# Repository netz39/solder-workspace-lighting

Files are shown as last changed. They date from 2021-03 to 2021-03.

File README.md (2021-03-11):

# solder workspace lighting
*Created with KiCad 5.1.9*

Dieses Repo beinhaltet die drei notwendigen Platinen, um den Lötarbeitsplatz im Netz39 ordentlich auszuleuchten.

## central_control
Überwacht die Temperatur aller LED-Projektoren und betreibt PWM-Dimming. Desweiteren bietet die Platine mehrere Schnittstellen (UART, SPI, I²C, CAN) für Erweiterungen an

## constant_current_source
Ein Buck-Converter liefert den voreingestellten konstanten Strom für die LEDs.

## high_power_LED:
Bestückt mit HighPower-LEDs, Thermistor und Kühlkörper.

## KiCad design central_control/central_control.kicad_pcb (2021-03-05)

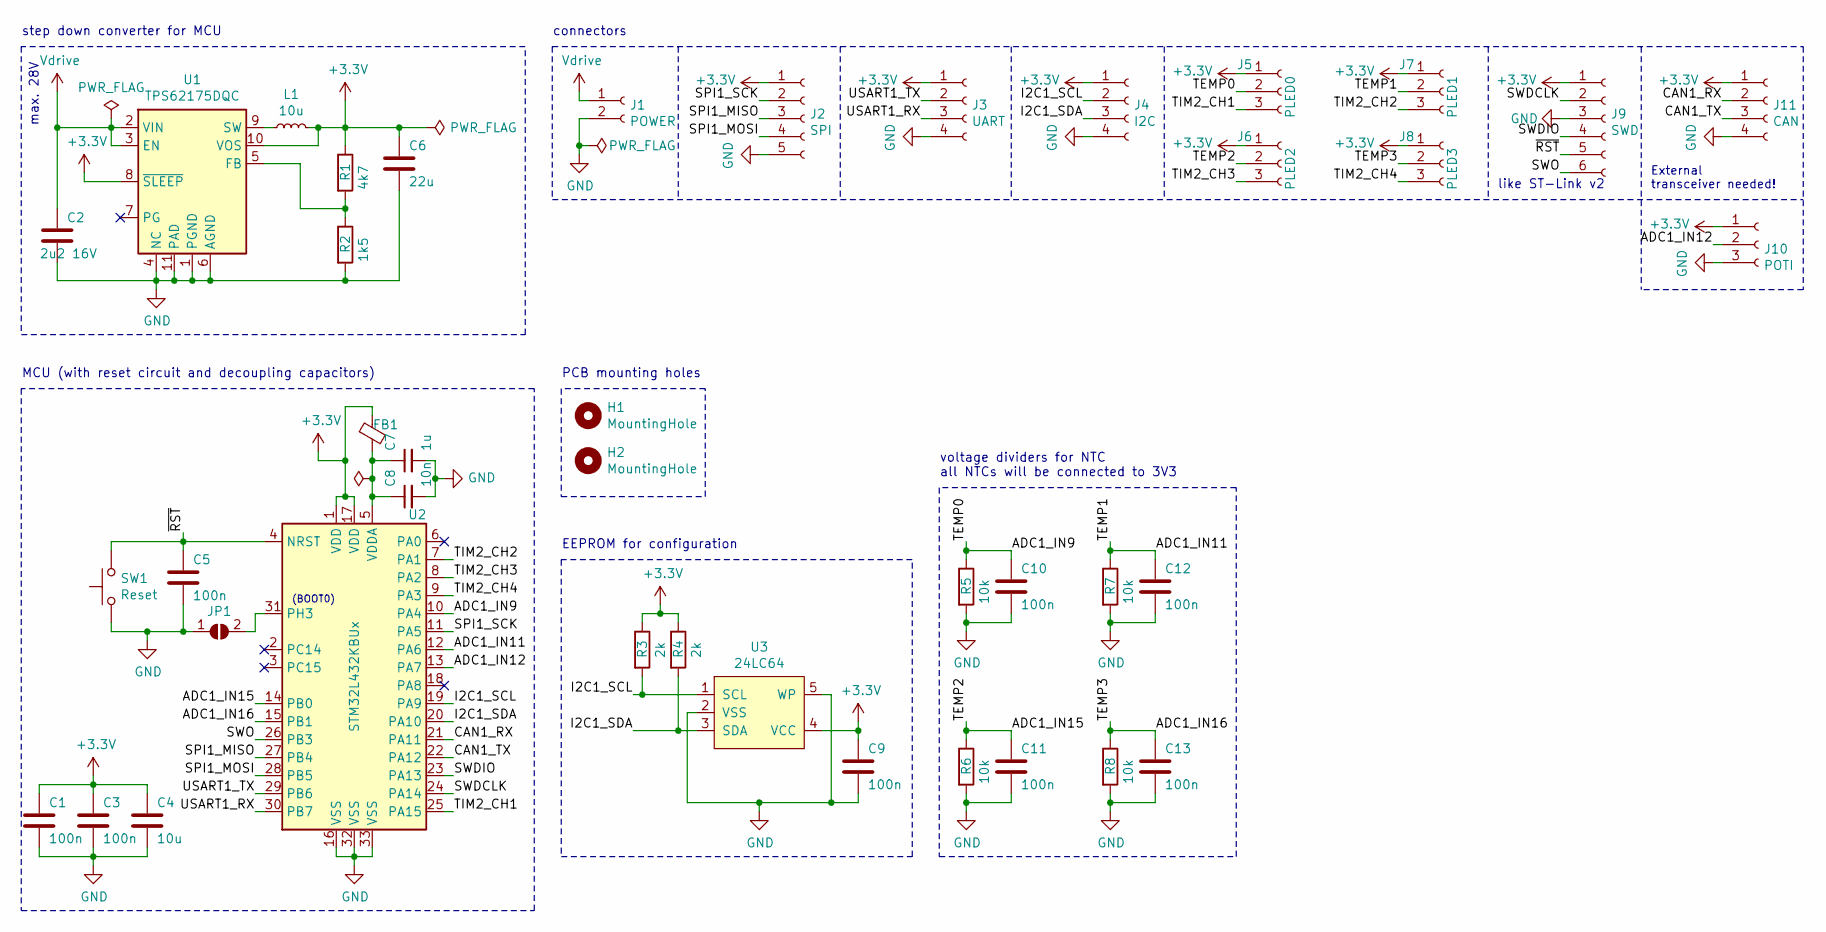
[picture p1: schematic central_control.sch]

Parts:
C1, C3, C5, C9, C10, C11, C12, C13: 100n; C_0603_1608Metric
C2: 2u2 16V; C_0603_1608Metric
C4: 10u; C_0805_2012Metric
C6: 22u; C_0805_2012Metric
C7: 1u; C_0603_1608Metric
C8: 10n; C_0603_1608Metric
FB1: Ferrite_Bead_Small; R_0603_1608Metric
H1, H2: MountingHole; MountingHole_2.7mm_M2.5_ISO14580
J1: POWER; Molex_PicoBlade_53047-0210_1x02_P1.25mm_Vertical
J2: SPI; Molex_PicoBlade_53047-0510_1x05_P1.25mm_Vertical
J3: UART; Molex_PicoBlade_53047-0410_1x04_P1.25mm_Vertical
J4: I2C; Molex_PicoBlade_53047-0410_1x04_P1.25mm_Vertical
J5: PLED0; Molex_PicoBlade_53047-0310_1x03_P1.25mm_Vertical
J6: PLED2; Molex_PicoBlade_53047-0310_1x03_P1.25mm_Vertical
J7: PLED1; Molex_PicoBlade_53047-0310_1x03_P1.25mm_Vertical
J8: PLED3; Molex_PicoBlade_53047-0310_1x03_P1.25mm_Vertical
J9: SWD; PinHeader_1x06_P2.54mm_Vertical
J10: POTI; Molex_PicoBlade_53047-0310_1x03_P1.25mm_Vertical
J11: CAN; Molex_PicoBlade_53047-0410_1x04_P1.25mm_Vertical
JP1: SolderJumper_2_Open; SolderJumper-2_P1.3mm_Open_TrianglePad1.0x1.5mm
L1: 10u; L_1210_3225Metric
R1: 4k7; R_0603_1608Metric
R2: 1k5; R_0603_1608Metric
R3, R4: 2k; R_0603_1608Metric
R5, R6, R7, R8: 10k; R_0603_1608Metric
SW1: SW_Push; PTS636_F-leads
U1: TPS62175DQC; WSON-10-1EP_2x3mm_P0.5mm_EP0.84x2.4mm_ThermalVias
U2: STM32L432KBUx; QFN-32-1EP_5x5mm_P0.5mm_EP3.45x3.45mm
U3: 24LC64; SOT-23-5

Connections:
+3V3: C1.1, C3.1, C4.1, C6.1, C9.1, FB1.1, J2.1, J3.1, J4.1, J5.1, J6.1, J7.1, J8.1, J9.1, J10.1, J11.1, L1.2, R1.1, R3.1, R4.1, U1.8 (~SLEEP), U1.10 (VOS), U2.1 (VDD), U2.17 (VDD), U3.4 (VCC)
/ADC1_IN9: C10.1, J5.2, R5.1, U2.10 (PA4)
/ADC1_IN11: C12.1, J7.2, R7.1, U2.12 (PA6)
/ADC1_IN12: J10.2, U2.13 (PA7)
/ADC1_IN15: C11.1, J6.2, R6.1, U2.14 (PB0)
/ADC1_IN16: C13.1, J8.2, R8.1, U2.15 (PB1)
/CAN1_RX: J11.2, U2.21 (PA11)
/CAN1_TX: J11.3, U2.22 (PA12)
/I2C1_SCL: J4.2, R3.2, U2.19 (PA9), U3.1 (SCL)
/I2C1_SDA: J4.3, R4.2, U2.20 (PA10), U3.3 (SDA)
/SPI1_MISO: J2.3, U2.27 (PB4)
/SPI1_MOSI: J2.4, U2.28 (PB5)
/SPI1_SCK: J2.2, U2.11 (PA5)
/SWDCLK: J9.2, U2.24 (PA14)
/SWDIO: J9.4, U2.23 (PA13)
/SWO: J9.6, U2.26 (PB3)
/TIM2_CH1: J5.3, U2.25 (PA15)
/TIM2_CH2: J7.3, U2.7 (PA1)
/TIM2_CH3: J6.3, U2.8 (PA2)
/TIM2_CH4: J8.3, U2.9 (PA3)
/USART1_RX: J3.3, U2.30 (PB7)
/USART1_TX: J3.2, U2.29 (PB6)
/~RST: C5.1, J9.5, SW1.2, U2.4 (NRST)
GND: C1.2, C2.2, C3.2, C4.2, C5.2, C6.2, C7.2, C8.2, C9.2, C10.2, C11.2, C12.2, C13.2, J1.2, J2.5, J3.4, J4.4, J9.3, J10.3, J11.4, JP1.1 (A), R2.2, R5.2, R6.2, R7.2, R8.2, SW1.1, U1.1 (PGND), U1.4 (NC), U1.6 (AGND), U1.11 (PAD), U2.16 (VSS), U2.32 (VSS), U2.33 (VSS), U3.2 (VSS), U3.5 (WP)
unnamed: C7.1, C8.1, FB1.2, U2.5 (VDDA)
unnamed: JP1.2 (B), U2.31 (PH3)
unnamed: L1.1, U1.9 (SW)
unnamed: R1.2, R2.1, U1.5 (FB)
Vdrive: C2.1, J1.1, U1.2 (VIN), U1.3 (EN)

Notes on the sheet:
max. 28V
step down converter for MCU
MCU (with reset circuit and decoupling capacitors)
connectors
PCB mounting holes
External transceiver needed!
EEPROM for configuration
voltage dividers for NTC all NTCs will be connected to 3V3
like ST-Link v2
(BOOT0)

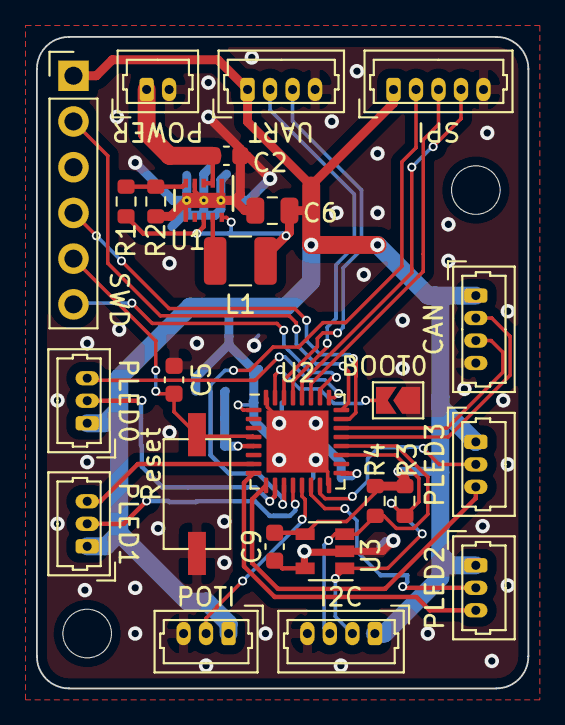
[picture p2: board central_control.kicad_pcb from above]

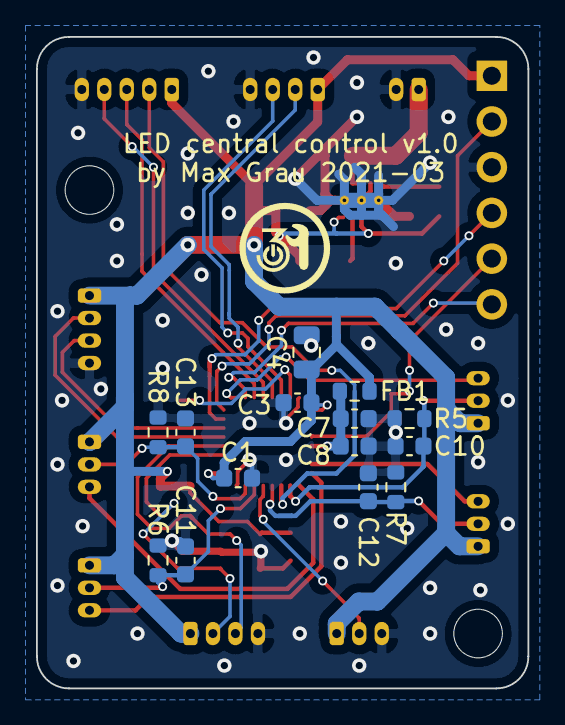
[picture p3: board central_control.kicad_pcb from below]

Board: 2 copper layers, 27.3 x 36.2 mm, 42 parts (15 on the bottom side), 29 nets.

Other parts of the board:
svg2mod: G***; netz39-logo

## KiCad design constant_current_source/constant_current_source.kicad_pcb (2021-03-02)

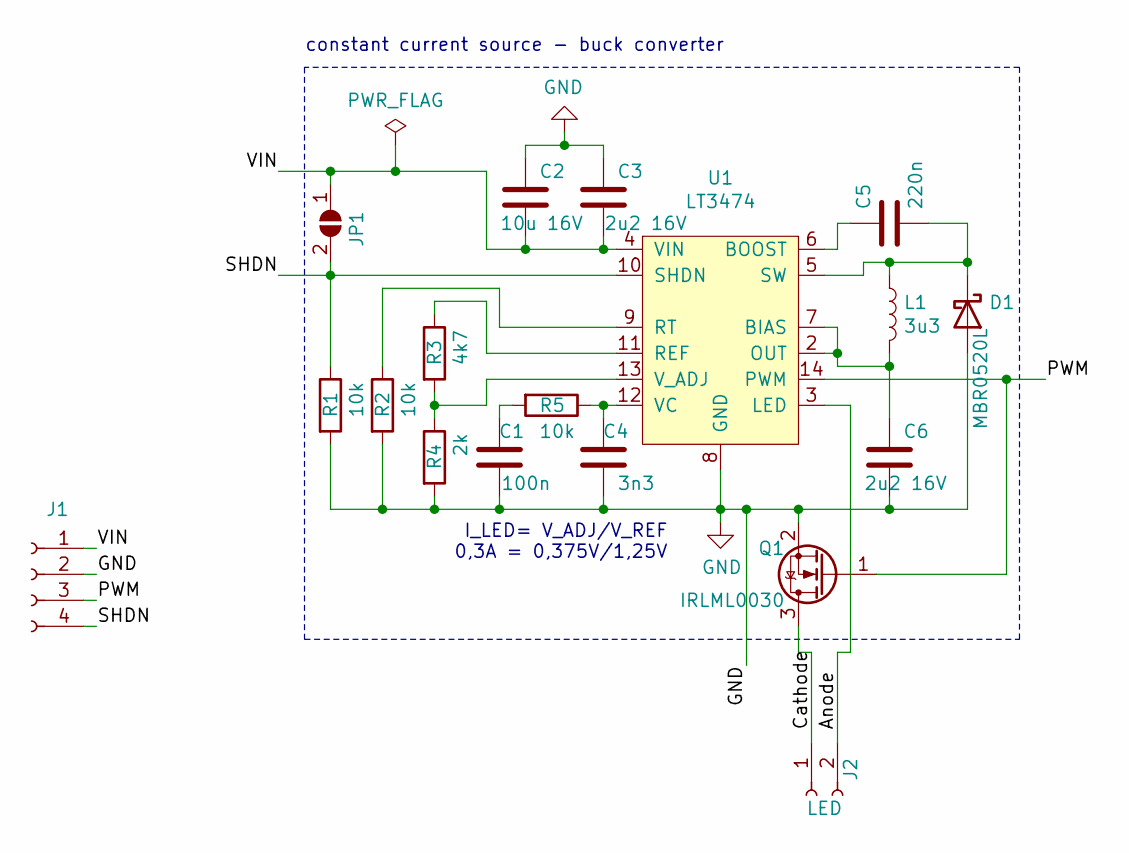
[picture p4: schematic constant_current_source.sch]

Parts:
C1: 100n; C_0603_1608Metric
C2: 10u 16V; C_0805_2012Metric
C3, C6: 2u2 16V; C_0603_1608Metric
C4: 3n3; C_0603_1608Metric
C5: 220n; C_0603_1608Metric
D1: MBR0520L; D_SOD-123
J1: Conn; Molex_PicoBlade_53047-0410_1x04_P1.25mm_Vertical
J2: LED; PinHeader_1x02_P2.54mm_Vertical
JP1: SolderJumper_2_Open; SolderJumper-2_P1.3mm_Open_TrianglePad1.0x1.5mm
L1: 3u3; L_Abracon_ASPI-3012S
Q1: IRLML0030; SOT-23
R1, R2, R5: 10k; R_0603_1608Metric
R3: 4k7; R_0603_1608Metric
R4: 2k; R_0603_1608Metric
U1: LT3474; TSSOP-16-1EP_4.4x5mm_P0.65mm

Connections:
/Anode: J2.2, U1.3 (LED)
/Cathode: J2.1, Q1.3 (D)
/PWM: J1.3, Q1.1 (G), U1.14 (PWM)
/SHDN: J1.4, JP1.2 (B), R1.1, U1.10 (SHDN)
/VIN: C2.2, C3.2, J1.1, JP1.1 (A), U1.4 (VIN)
GND: C1.1, C2.1, C3.1, C4.1, C6.2, D1.2 (A), J1.2, Q1.2 (S), R1.2, R2.2, R4.2, U1.8 (GND), U1.15 (GND), U1.17 (GND)
unnamed: C1.2, R5.2
unnamed: C4.2, R5.1, U1.12 (VC)
unnamed: C5.1, U1.6 (BOOST)
unnamed: C5.2, D1.1 (K), L1.1, U1.5 (SW)
unnamed: C6.1, L1.2, U1.2 (OUT), U1.7 (BIAS)
unnamed: R2.1, U1.9 (RT)
unnamed: R3.1, U1.11 (REF)
unnamed: R3.2, R4.1, U1.13 (V_ADJ)

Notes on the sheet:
I_LED= V_ADJ/V_REF 0,3A = 0,375V/1,25V
constant current source - buck converter

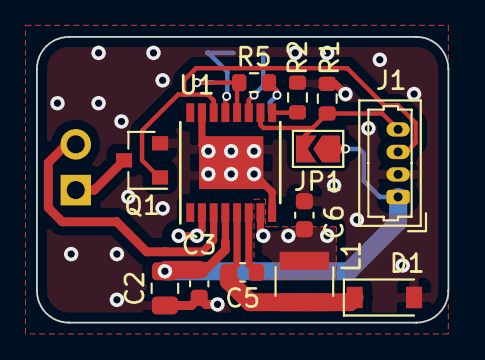
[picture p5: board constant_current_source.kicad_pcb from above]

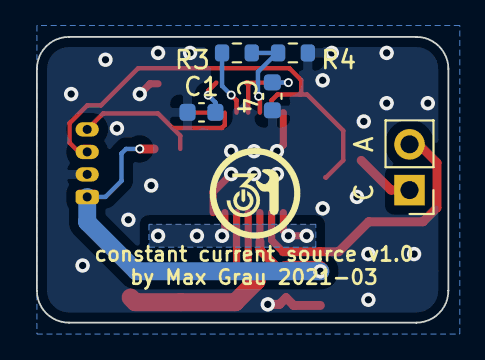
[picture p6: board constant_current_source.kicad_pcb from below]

Board: 2 copper layers, 22.9 x 15.9 mm, 19 parts (6 on the bottom side), 14 nets.

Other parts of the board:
svg2mod: G***; netz39-logo

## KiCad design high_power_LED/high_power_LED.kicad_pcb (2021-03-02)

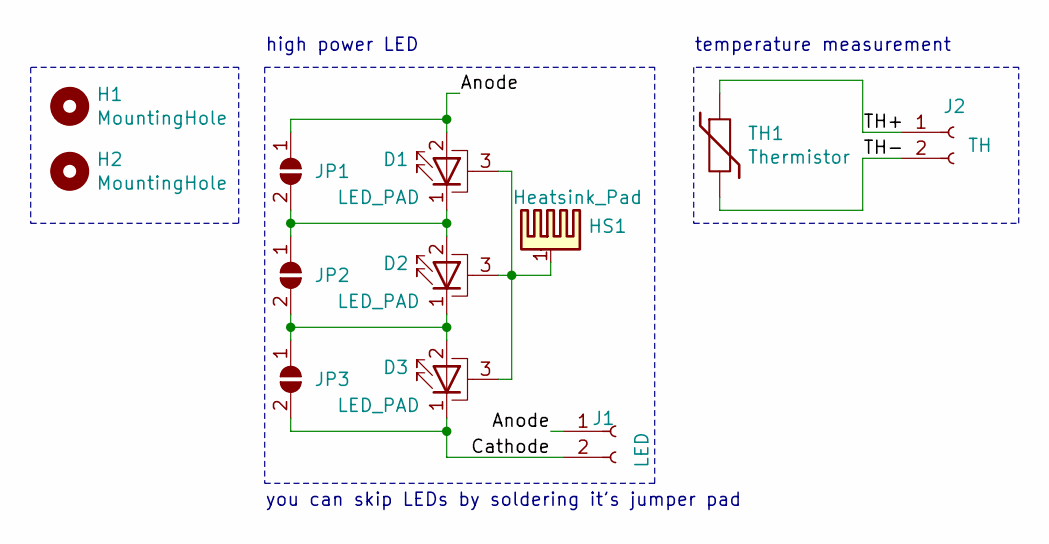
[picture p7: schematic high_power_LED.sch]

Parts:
D1, D2, D3: LED_PAD; Cree-XLamp-MX6
H1, H2: MountingHole; MountingHole_2.7mm_M2.5_ISO14580
HS1: Heatsink_Pad; Heatsink_AAVID_573300D00010G_TO-263
J1: LED; PinHeader_1x02_P2.54mm_Vertical
J2: TH; Molex_PicoBlade_53047-0210_1x02_P1.25mm_Vertical
JP1, JP2, JP3: SolderJumper_2_Open; SolderJumper-2_P1.3mm_Open_TrianglePad1.0x1.5mm
TH1: Thermistor; R_0603_1608Metric

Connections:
/Anode: D1.2 (A), J1.1, JP1.1 (A)
/Cathode: D3.1 (K), J1.2, JP3.2 (B)
/TH+: J2.1, TH1.1
/TH-: J2.2, TH1.2
unnamed: D1.1 (K), D2.2 (A), JP1.2 (B), JP2.1 (A)
unnamed: D1.3 (PAD), D2.3 (PAD), D3.3 (PAD), HS1.1
unnamed: D2.1 (K), D3.2 (A), JP2.2 (B), JP3.1 (A)

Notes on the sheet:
you can skip LEDs by soldering it's jumper pad
temperature measurement
high power LED

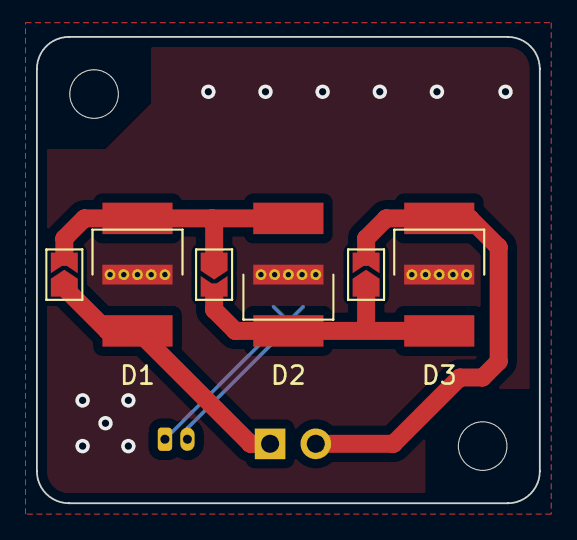
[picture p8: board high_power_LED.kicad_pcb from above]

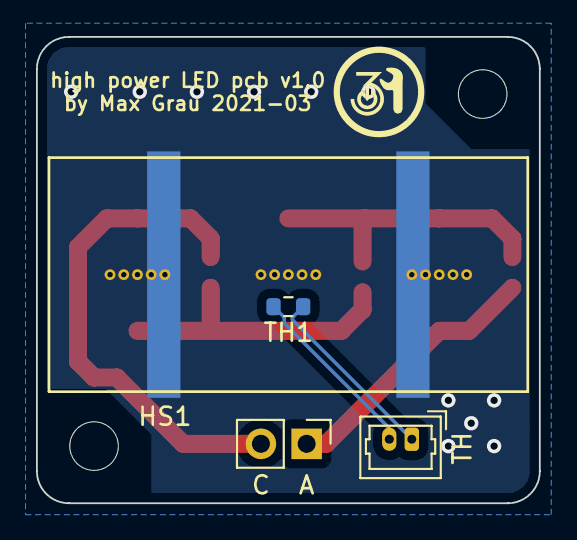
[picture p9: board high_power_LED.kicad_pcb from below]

Board: 2 copper layers, 27.9 x 25.9 mm, 13 parts (5 on the bottom side), 7 nets.

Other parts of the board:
svg2mod: G***; netz39-logo

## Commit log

2021-02-05 Add constant current source
    [central_control.sch, constant_current_source.sch, high_power_LED.sch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]
2021-02-07 Add datasheet and footprint to LT3474
    [constant_current_source.sch]
2021-02-07 Add PWM dimming
    [constant_current_source.sch]
2021-02-07 Choose STM32L011D3
    [central_control.sch]
2021-02-15 Finish sheets
    [central_control.sch, constant_current_source.sch, high_power_LED.sch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]
2021-02-16 Fix mosfet symbol
    [constant_current_source.sch]
2021-02-17 Add STM32G0 microcontroller
2021-02-17 Replace MCU and add CAN Flexible Datarate. Close #1
    [central_control.sch]
2021-02-17 Add EEPROM for configuration's sake
    [central_control.sch]
2021-02-18 Add voltage dividers for temperature measurement and optional connector for poti
    [central_control.sch]
2021-02-20 Replace MCU again (with STM32L431KB) STM32G0B1 is not available on digikey/mouser
    [central_control.sch]
2021-02-22 Update MCU
    [central_control.sch]
2021-02-26 Annotate sheets and assign symbols
    [central_control.sch, constant_current_source.sch, high_power_LED.sch]
2021-03-02 Split project into individual projects and reannotate sheets
    [central_control.kicad_pcb, central_control.sch, constant_current_source.kicad_pcb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]
2021-03-02 Finish high power led pcb
    [high_power_LED.kicad_pcb, high_power_LED.sch]
2021-03-02 Move projects into subfolders
    [central_control.kicad_pcb, central_control.sch, constant_current_source.kicad_pcb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]
2021-03-02 See commit before
    [constant_current_source.kicad_pcb, constant_current_source.sch]
2021-03-02 Finish constant current source pcb
    [constant_current_source.kicad_pcb, constant_current_source.sch]
2021-03-05 Finish central control PCB
    [central_control.kicad_pcb, central_control.sch]
2021-03-11 „README.md“ ändern
